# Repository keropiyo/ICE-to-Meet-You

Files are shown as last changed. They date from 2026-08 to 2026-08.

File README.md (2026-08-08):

# ICE-to-Meet-You
### Imaginative Creative Engineering
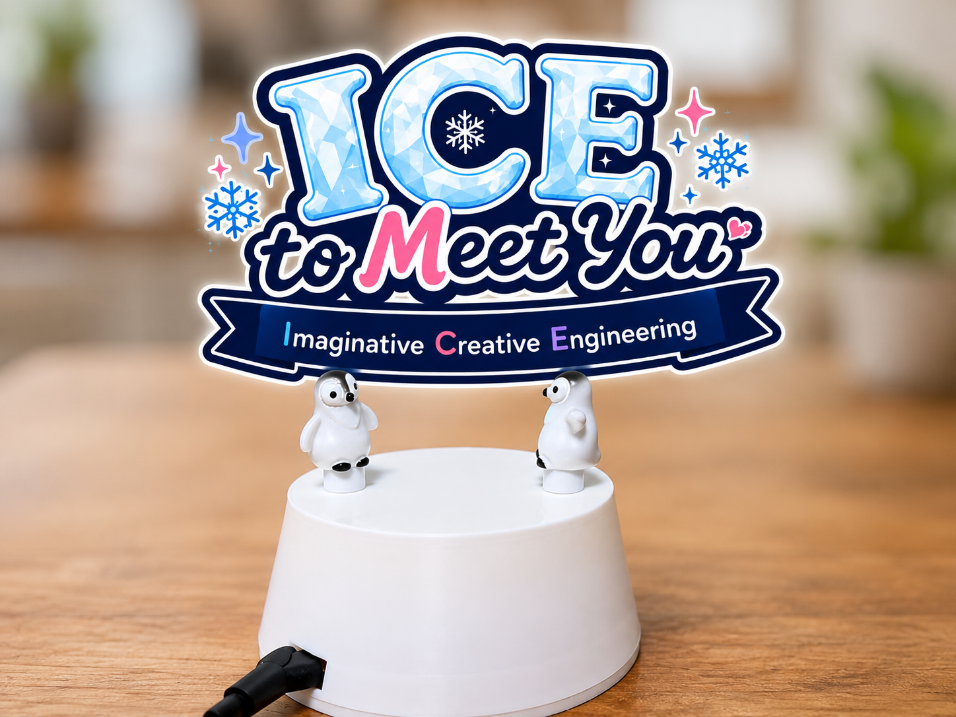
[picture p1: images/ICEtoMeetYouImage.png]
ICE to Meet You Logo

**A magnetic dancing penguin music box powered by M5Stamp C3U with MIDI music.**

## About

Two little penguins meet for the first time on the ice.  
Using the force of magnets, they spin and dance together.

**ICE to Meet You** is a small electronic music box inspired by the classic ballerina music boxes of the past.

The nostalgic mechanism has been reimagined using an **M5Stamp C3U**, magnets, a motor, and MIDI music.

When the music begins, the M5Stamp C3U controls the motor beneath the iceberg, making the penguins dance on the ice.

---

## ICE = Imaginative Creative Engineering

The name **ICE to Meet You** is a play on “Nice to meet you.”

But **ICE** has another meaning:

**I.C.E. = Imaginative Creative Engineering**

For this project, it means taking a familiar mechanism from the past, imagining a new way to use it, and recreating it with modern technology.

The ballerina becomes two penguins.

The stage becomes an iceberg.

And the mechanical music box becomes an electronic music box powered by M5Stack.

---

## How It Works
A magnet is attached to a rotating mechanism underneath the iceberg.

Magnets are also attached to the penguins.

When the motor rotates the magnet beneath the surface, magnetic force makes the penguins move and spin across the ice.

The **M5Stamp C3U** controls the motor, including the timing of when the penguins start and stop dancing.

At the same time, the M5Stamp C3U sends MIDI data to an **M5Stack Unit Synth**.

The Unit Synth plays the music through its built-in speaker.

The music uses a **Music Box** instrument with reverb to give it a nostalgic, sparkling sound.

---

## Music

This project has its own original theme song:

### “ICE to Meet You”

The original song was created with the help of **Suno**.

The music was then converted to MIDI and simplified for playback on the M5Stack Unit Synth.

The M5Stamp C3U sends the MIDI notes to the Unit Synth while controlling the movement of the penguins.

This allows the music and the dance to become one small performance.

### Lyrics

> On a little piece of ice,  
> I met someone oh-so-nice,  
> You looked at me, I looked at you,  
> And suddenly the whole world flew!
>
> Round and round, we softly glide,  
> Two little penguins, side by side,  
> Round and round, just me and you,  
> Underneath the sky so blue.
>
> Nice to meet you,  
> **ICE to Meet You!**  
> Round we go, just me and you!  
> **Imaginative, Creative, Engineering,**  
> Making little dreams come true!

---
## Hardware

- M5Stamp C3U
- M5Stack Unit Synth (SAM2695)
- Mini DC gear motor
- 2SC1815 transistor
- 1N4007 diode
- Resistor
- Magnets
- USB 5V power supply
- 3D-printed iceberg  (original design in Autodesk Fusion)
- Two penguin figurines

---

## System
```text
                    ┌── MIDI ──> M5Stack Unit Synth
                    │                │
                    │                └──> Built-in Speaker
                    │
M5Stamp C3U ────────┤
                    │
                    └── GPIO ──> Transistor ──> DC Motor
                                                │
                                                ▼
                                             Magnet
                                                │
                                                ▼
                                      Dancing Penguins
```

## 3D Models

The iceberg base and the two penguins are original 3D models designed in Autodesk Fusion specifically for ICE to Meet You.

All 3D model files used in this project are available in the [`3D-Model`](3D-Model/) folder.

The iceberg base is designed to house the M5Stamp C3U, motor, magnets, and other electronic components.

Magnets are embedded in the penguins. As the magnet underneath the surface rotates, magnetic force makes the penguins move and dance on the ice.

The models can be downloaded and 3D printed to recreate ICE to Meet You.

## Story

Two little penguins meet for the first time on the ice.

They look at each other.

The music begins.

And then...

ICE to Meet You!

The two penguins begin to dance together.

M5Stack Global Innovation Contest 2026

ICE to Meet You was created for the
M5Stack Global Innovation Contest 2026.

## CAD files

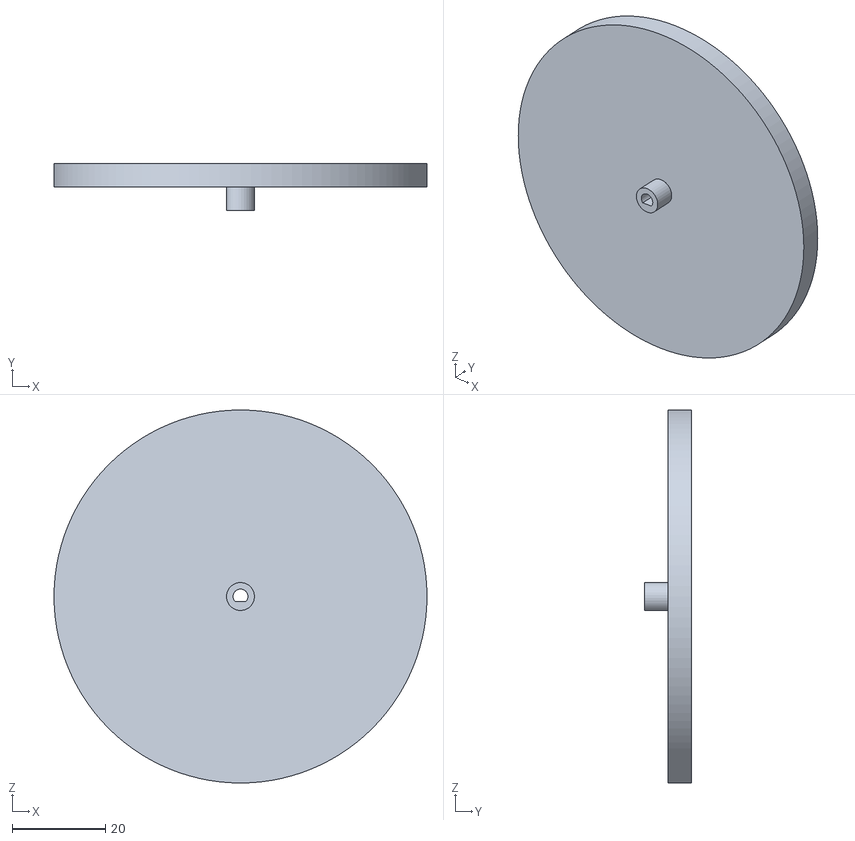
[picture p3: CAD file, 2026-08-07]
3d-models/ICEtoMeetYoutool1.stl
80.0 x 10.0 x 80.0

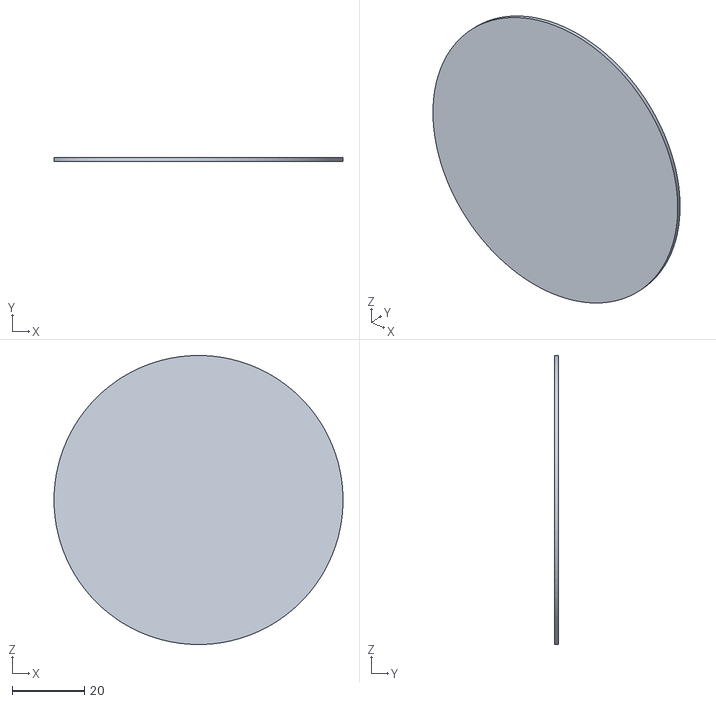
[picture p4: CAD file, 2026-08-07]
3d-models/ICEtoMeetYoutool2.stl
80.0 x 1.00 x 80.0

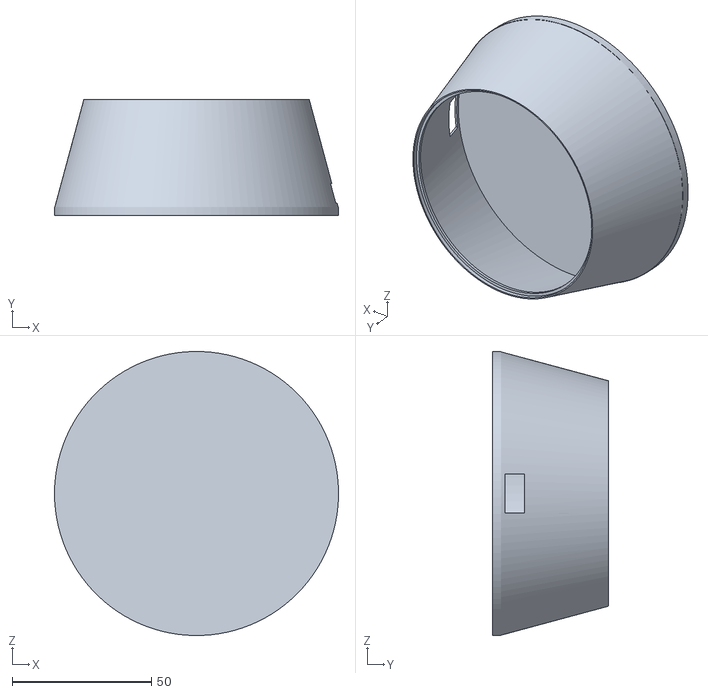
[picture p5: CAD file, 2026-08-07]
3d-models/ICEtoMeetYoucase.stl
102.0 x 41.5 x 102.0

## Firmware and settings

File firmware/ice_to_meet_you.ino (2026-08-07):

#include <Arduino.h>

HardwareSerial MidiSerial(1);

const int MIDI_TX_PIN = 4;   // Unit Synth RX
const int MOTOR_PIN   = 5;   // 1kΩ -> 2SC1815 base
const byte MIDI_CHANNEL = 0;
const byte MUSIC_BOX_PROGRAM = 10;
const byte REVERB_LEVEL = 120;
const byte VOLUME_LEVEL = 120;  // MIDI channel volume (0-127)

// Motor PWM settings
const int MOTOR_PWM_FREQ = 5000;
const int MOTOR_PWM_RES  = 8;      // 0-255
const int MOTOR_SPEED    = 200;    // 通常回転：小さいほどゆっくり
const int MOTOR_BOOST    = 220;    // 始動時だけ少し強く
const int BOOST_TIME_MS  = 250;    // 始動ブースト時間

struct MidiEvent {
  uint16_t waitMs;
  uint8_t note;
  uint8_t velocity;
  uint8_t noteOn;
};

void send3(byte status, byte data1, byte data2) {
  MidiSerial.write(status);
  MidiSerial.write(data1);
  MidiSerial.write(data2);
}

void programChange(byte channel, byte program) {
  MidiSerial.write(0xC0 | (channel & 0x0F));
  MidiSerial.write(program);
}

void controlChange(byte channel, byte control, byte value) {
  send3(0xB0 | (channel & 0x0F), control, value);
}

void noteOn(byte note, byte velocity) {
  send3(0x90 | MIDI_CHANNEL, note, velocity);
}

void noteOff(byte note) {
  send3(0x80 | MIDI_CHANNEL, note, 0);
}

const MidiEvent song[] = {
  {162, 67, 81, 1},
  {0, 83, 62, 1},
  {303, 83, 0, 0},
  {34, 71, 77, 1},
  {0, 74, 63, 1},
  {255, 67, 0, 0},
  {70, 71, 0, 0},
  {0, 71, 63, 1},
  {0, 83, 71, 1},
  {128, 74, 0, 0},
  {127, 83, 0, 0},
  {70, 62, 101, 1},
  {12, 83, 45, 1},
  {92, 71, 0, 0},
  {152, 83, 0, 0},
  {69, 62, 0, 0},
  {0, 62, 78, 1},
  {0, 74, 64, 1},
  {12, 71, 66, 1},
  {324, 74, 0, 0},
  {1, 74, 82, 1},
  {36, 71, 0, 0},
  {139, 79, 72, 1},
  {12, 74, 76, 1},
  {1, 74, 0, 0},
  {33, 62, 0, 0},
  {94, 79, 0, 0},
  {12, 74, 0, 0},
  {0, 67, 58, 1},
  {0, 71, 73, 1},
  {0, 83, 58, 1},
  {266, 67, 0, 0},
  {47, 83, 0, 0},
  {11, 71, 0, 0},
  {0, 71, 82, 1},
  {0, 74, 61, 1},
  {279, 74, 0, 0},
  {47, 88, 73, 1},
  {11, 71, 0, 0},
  {0, 71, 71, 1},
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
};

const size_t SONG_EVENT_COUNT = sizeof(song) / sizeof(song[0]);

void allNotesOff() {
  controlChange(MIDI_CHANNEL, 123, 0);
}

// 曲の時間に合わせてペンギンを踊らせる
// OFF→ONになった瞬間だけ強めに250ms、その後ゆっくり回す
void updateMotor(uint32_t t) {
  static bool previousOn = false;
  static uint32_t motorStartedAt = 0;

  bool on =
      (t >=  4000 && t < 14000) ||  // 出会って踊り始める
      (t >= 16000 && t < 28000) ||  // もう一度くるくる
      (t >= 31000 && t < 43000) ||  // 中盤
      (t >= 46000 && t < 57500);    // ラストダンス

  if (on && !previousOn) {
    motorStartedAt = t;
  }

  if (!on) {
    ledcWrite(MOTOR_PIN, 0);
  } else if (t - motorStartedAt < BOOST_TIME_MS) {
    ledcWrite(MOTOR_PIN, MOTOR_BOOST);
  } else {
    ledcWrite(MOTOR_PIN, MOTOR_SPEED);
  }

  previousOn = on;
}

void playSong() {
  allNotesOff();

  uint32_t songTime = 0;
  ledcWrite(MOTOR_PIN, 0);

  for (size_t i = 0; i < SONG_EVENT_COUNT; i++) {
    uint16_t waitMs = song[i].waitMs;

    // 長めの待ち時間でもモーターのタイミングを逃さないよう、
    // 10msずつ進めながら状態を更新する
    while (waitMs > 0) {
      uint16_t step = (waitMs > 10) ? 10 : waitMs;
      delay(step);
      songTime += step;
      waitMs -= step;
      updateMotor(songTime);
    }

    if (song[i].noteOn) {
      noteOn(song[i].note, song[i].velocity);
    } else {
      noteOff(song[i].note);
    }
  }

  ledcWrite(MOTOR_PIN, 0);
  allNotesOff();
}

void setup() {
  // G5をモーター用PWM出力にする
  ledcAttach(MOTOR_PIN, MOTOR_PWM_FREQ, MOTOR_PWM_RES);
  ledcWrite(MOTOR_PIN, 0);

  MidiSerial.begin(31250, SERIAL_8N1, -1, MIDI_TX_PIN);
  delay(700);

  programChange(MIDI_CHANNEL, MUSIC_BOX_PROGRAM);
  controlChange(MIDI_CHANNEL, 7, VOLUME_LEVEL);
  controlChange(MIDI_CHANNEL, 91, REVERB_LEVEL);
  delay(200);

  playSong();
}

void loop() {
}
